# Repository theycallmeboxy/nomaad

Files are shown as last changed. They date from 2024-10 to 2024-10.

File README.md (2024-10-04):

# Nomaad
*A 11 column ortho/alpha gaming keyboard for gamers*

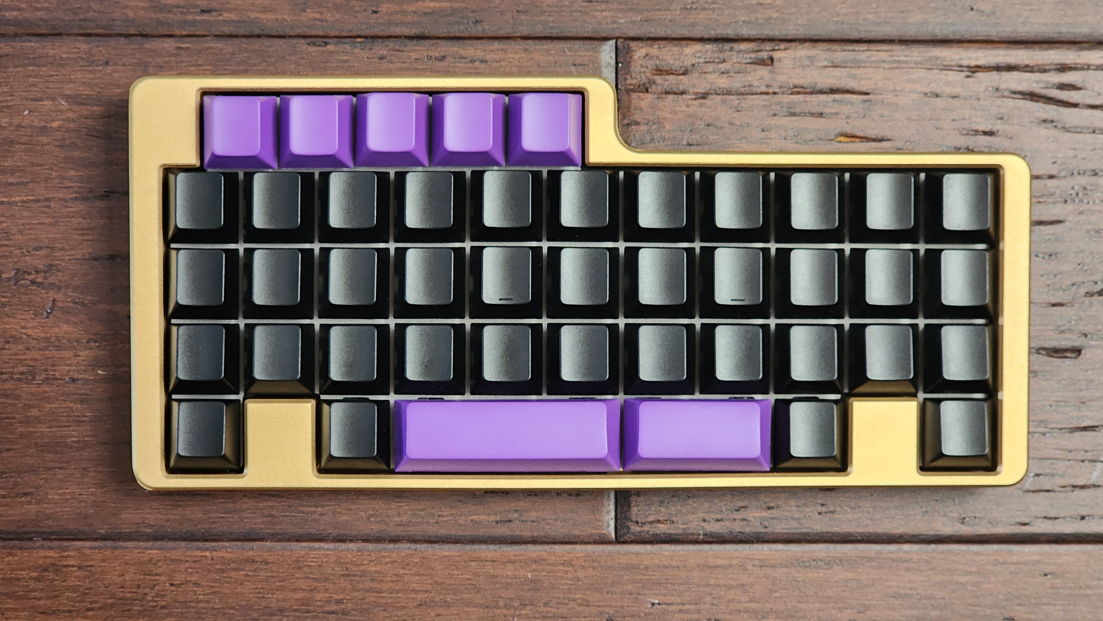
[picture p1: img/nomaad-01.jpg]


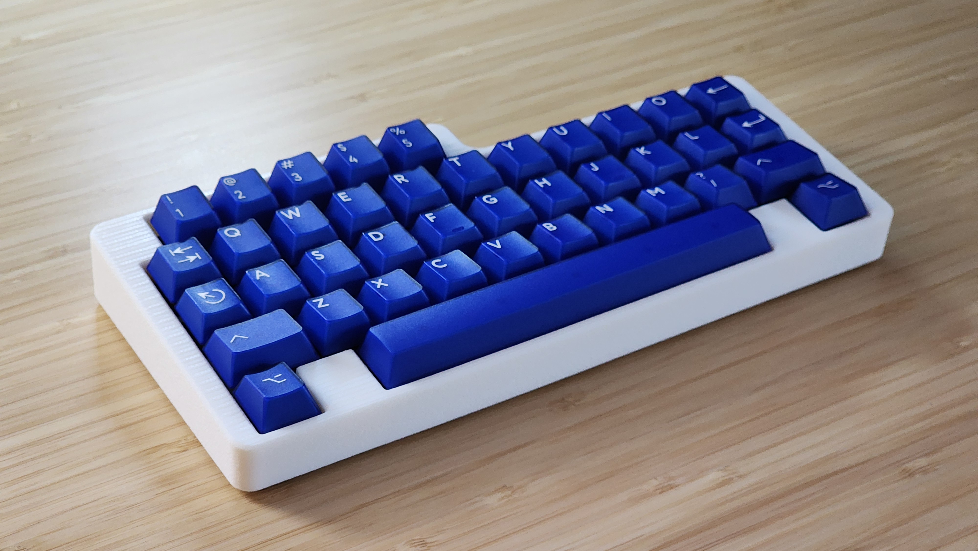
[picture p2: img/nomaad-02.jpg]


**[KLE](https://www.keyboard-layout-editor.com/##@_name=Nomaad%20Vial&author=theycallmeboxy%3B&@_x:0.5%3B&=0,1&=0,2&=0,3&=0,4&=0,5%3B&@=1,0&=1,1&=1,2&=1,3&=1,4&=1,5&=1,6&=1,7&=1,8&=1,9&=1,10%3B&@=2,0&=2,1&=2,2&=2,3&=2,4&=2,5&=2,6&=2,7&=2,8&=2,9&=2,10%3B&@_c=%2300c5ff%3B&=3,0%0A%0A%0A0,0&=3,1%0A%0A%0A0,0&=3,2%0A%0A%0A0,0&=3,3%0A%0A%0A0,0&=3,4%0A%0A%0A0,0&=3,5%0A%0A%0A0,0&=3,6%0A%0A%0A0,0&=3,7%0A%0A%0A0,0&=3,8%0A%0A%0A0,0&=3,9%0A%0A%0A0,0&=3,10%0A%0A%0A0,0%3B&@_c=%23cccccc%3B&=4,0&_x:1&c=%23ffb80c%3B&=4,1%0A%0A%0A1,0&_w:3%3B&=4,3%0A%0A%0A1,0&_w:2%3B&=4,6%0A%0A%0A1,0&=4,7%0A%0A%0A1,0&_x:1&c=%23cccccc%3B&=4,10%3B&@_y:0.5&c=%2300c5ff&w:1.5%3B&=3,0%0A%0A%0A0,1&=3,1%0A%0A%0A0,1&=3,2%0A%0A%0A0,1&=3,3%0A%0A%0A0,1&=3,4%0A%0A%0A0,1&=3,5%0A%0A%0A0,1&=3,6%0A%0A%0A0,1&=3,7%0A%0A%0A0,1&=3,8%0A%0A%0A0,1&_w:1.5%3B&=3,10%0A%0A%0A0,1%3B&@_y:0.25&x:2&c=%23ffb80c&w:7%3B&=4,3%0A%0A%0A1,1)**

## Production Files:

*(Click a link then click download icon in the top right to save a given file to your computer.)*

> [!CAUTION]
> I will assume no responsibility for any cost, damage, or sads resulting from trying to make one of my dumb projects. This project has no implicit support, neither moral nor technical.
> 
> **I'm not a doctor. This is not medical advice. I'm also only a network engineer. You assume all liability in using or reproducing these files.**

Case:
- [Case .stl file](https://github.com/theycallmeboxy/nomaad/blob/main/models/case/nomaad-case.stl)
- [Case .step file](https://github.com/theycallmeboxy/nomaad/blob/main/models/case/nomaad-case.step)

Plate:
- [Ortho stagger plate .dxf file](https://github.com/theycallmeboxy/nomaad/blob/main/models/plate/nomaad-plate_ortho.dxf)
- [Alpha stagger plate .dxf file](https://github.com/theycallmeboxy/nomaad/blob/main/models/plate/nomaad-plate_alpha.dxf)

PCB:
> [!NOTE]
> Version 1 was produced (as prototype 1) without any identified issues.  The gerbers were regenerated to indicate version 1 on the silk and the bom and positions files should be fixed to order as-is.  I have not produced these files yet, but they should be good to go.

- [PCB gerbers .zip file](https://github.com/theycallmeboxy/nomaad/blob/main/pcb/nomaad%20v1/production/nomaad.zip)
- [BOM .csv file](https://github.com/theycallmeboxy/nomaad/blob/main/pcb/nomaad%20v1/production/bom.csv)
- [Positions .csv file](https://github.com/theycallmeboxy/nomaad/blob/main/pcb/nomaad%20v1/production/positions.csv)

Firmware:
- [VIAL Firmware .bin file](https://github.com/theycallmeboxy/nomaad/blob/main/firmware/vial/binary/boxy_nomaad_vial.bin)
  
## Build Notes:

I have made with FDM and CNC aluminum to good effect.  Another 40s member had a resin version manufactured successfully.

**Additional materials:**
 
  - About 18" of .139" (3.53mm) cross section o-ring cord [like this 50A cord](https://www.theoringstore.com/store/index.php?main_page=product_info&cPath=117_527&products_id=18618) or [this 70A cord](https://www.theoringstore.com/store/index.php?main_page=product_info&cPath=117_119&products_id=5058); if you don't want to buy bulk cord, you can cut up an o-ring of like 6" or bigger diameter.
  - 4 SKUF feet like these  [like these](https://keeb.io/products/skuf-silicone-rubber-keyboard-feet).

**Build instructions:**

1. Apply feet to the cutouts.
2. Install stabs if you're into that. 
3. Install switches into the plate and PCB.
4. Solder it up.
5. Friction fit the o-ring cord between the plate and PCB in the positions highlighted in red:

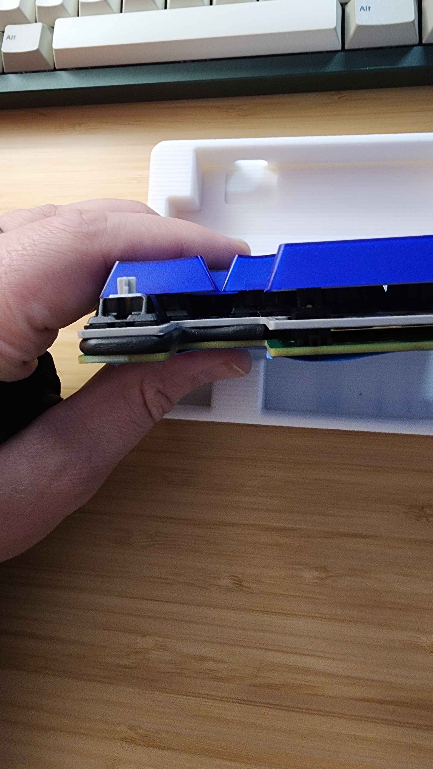
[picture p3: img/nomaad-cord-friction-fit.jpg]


keyborb

6. Insert the assembled PCB number keys first into the case at an angle while aligning the USB port with the cutout.
7. Press the top of the PCB in place, then press in the bottom side (if your cord isn't fully seated, sticks out on the corners, or otherwise catches going in, grab some tweezers and help it stay in between the plate and PCB). 
8. If you need to remove the PCB, pull a few caps off and use a switch puller on the soldered switches.

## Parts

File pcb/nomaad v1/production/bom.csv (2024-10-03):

Designator | Footprint | Quantity | Value | LCSC Part #
BOOT1, RST1 | SW_SPST_TL3342 | 2 | SW_SPST | C318884
C1, C3, C4, C5, C6, C7, C8 | 0402 | 7 | 100nF | C1525
C10, C9 | 0402 | 2 | 1uF | C52923
C2 | 0603 | 1 | 10uF | C19702
D1, D10, D11, D12, D13, D14, D15, D16, D17, D18, D19, D2, D20, D21, D22, D23, D24, D25, D26, D27, D28, D29, D3, D30, D31, D32, D33, D34, D35, D36, D37, D38, D39, D4, D40, D41, D42, D43, D44, D5, D6, D7, D8, D9 | D_SOD-123 | 44 | D | C81598
F1 | 1206 | 1 | 500mA | C369160
J1 | USB_C_Receptacle_HRO_TYPE-C-31-M-12 | 1 | USB_C_Receptacle_USB2.0 | C165948
R1, R2, R3, R4 | 0402 | 4 | 5.1k | C25905
U1 | LQFP-48_7x7mm_P0.5mm | 1 | STM32F072CBT6 | C81720
U2 | SOT-143 | 1 | PRTR5V0U2X | C2827688
U3 | SOT-23 | 1 | XC6206PxxxMR-Regulator_Linear | C5446

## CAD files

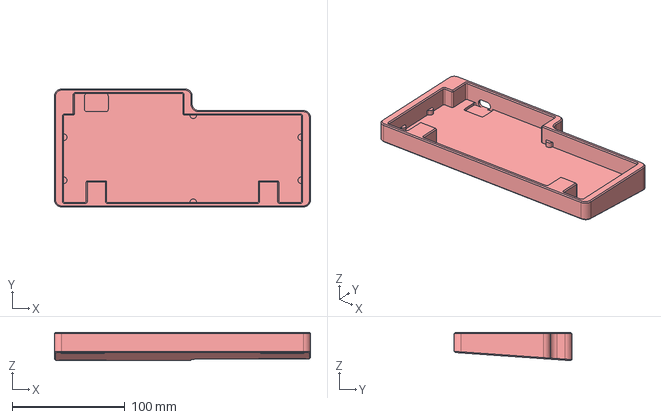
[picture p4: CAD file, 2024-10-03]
models/case/nomaad-case.step
226.6 x 104.3 x 25.0 mm

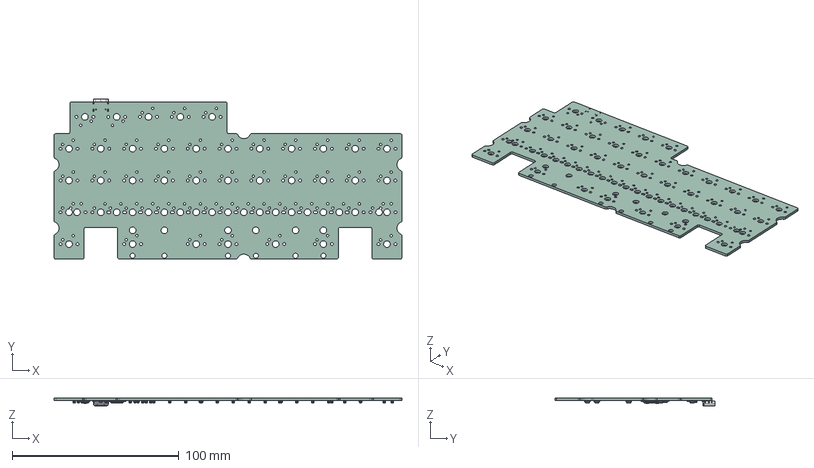
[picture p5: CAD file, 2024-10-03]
models/pcb/nomaad.step
208.5 x 96.0 x 4.85 mm
C_0402_1005Metric x 9
D_SOD_123 x 44
Fuse_1206_3216Metric
SW_SPST_TL3342 x 2
SOT_143
R_0402_1005Metric x 4
LQFP_48_7x7mm_P05mm
CON_TYPE-C-31-M-12 v3
C_0603_1608Metric
SOT_23
nomaad_PCB

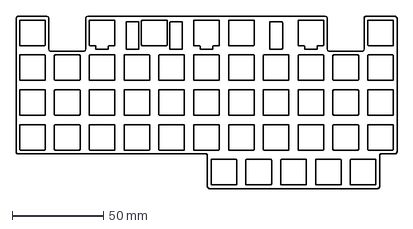
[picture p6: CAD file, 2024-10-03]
models/plate/nomaad-plate_ortho.dxf
208.5 x 94.2 mm

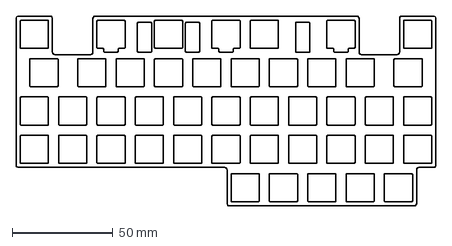
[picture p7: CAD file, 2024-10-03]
models/plate/nomaad-plate_alpha.dxf
208.5 x 94.2 mm

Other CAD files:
models/case/nomaad-case.stl

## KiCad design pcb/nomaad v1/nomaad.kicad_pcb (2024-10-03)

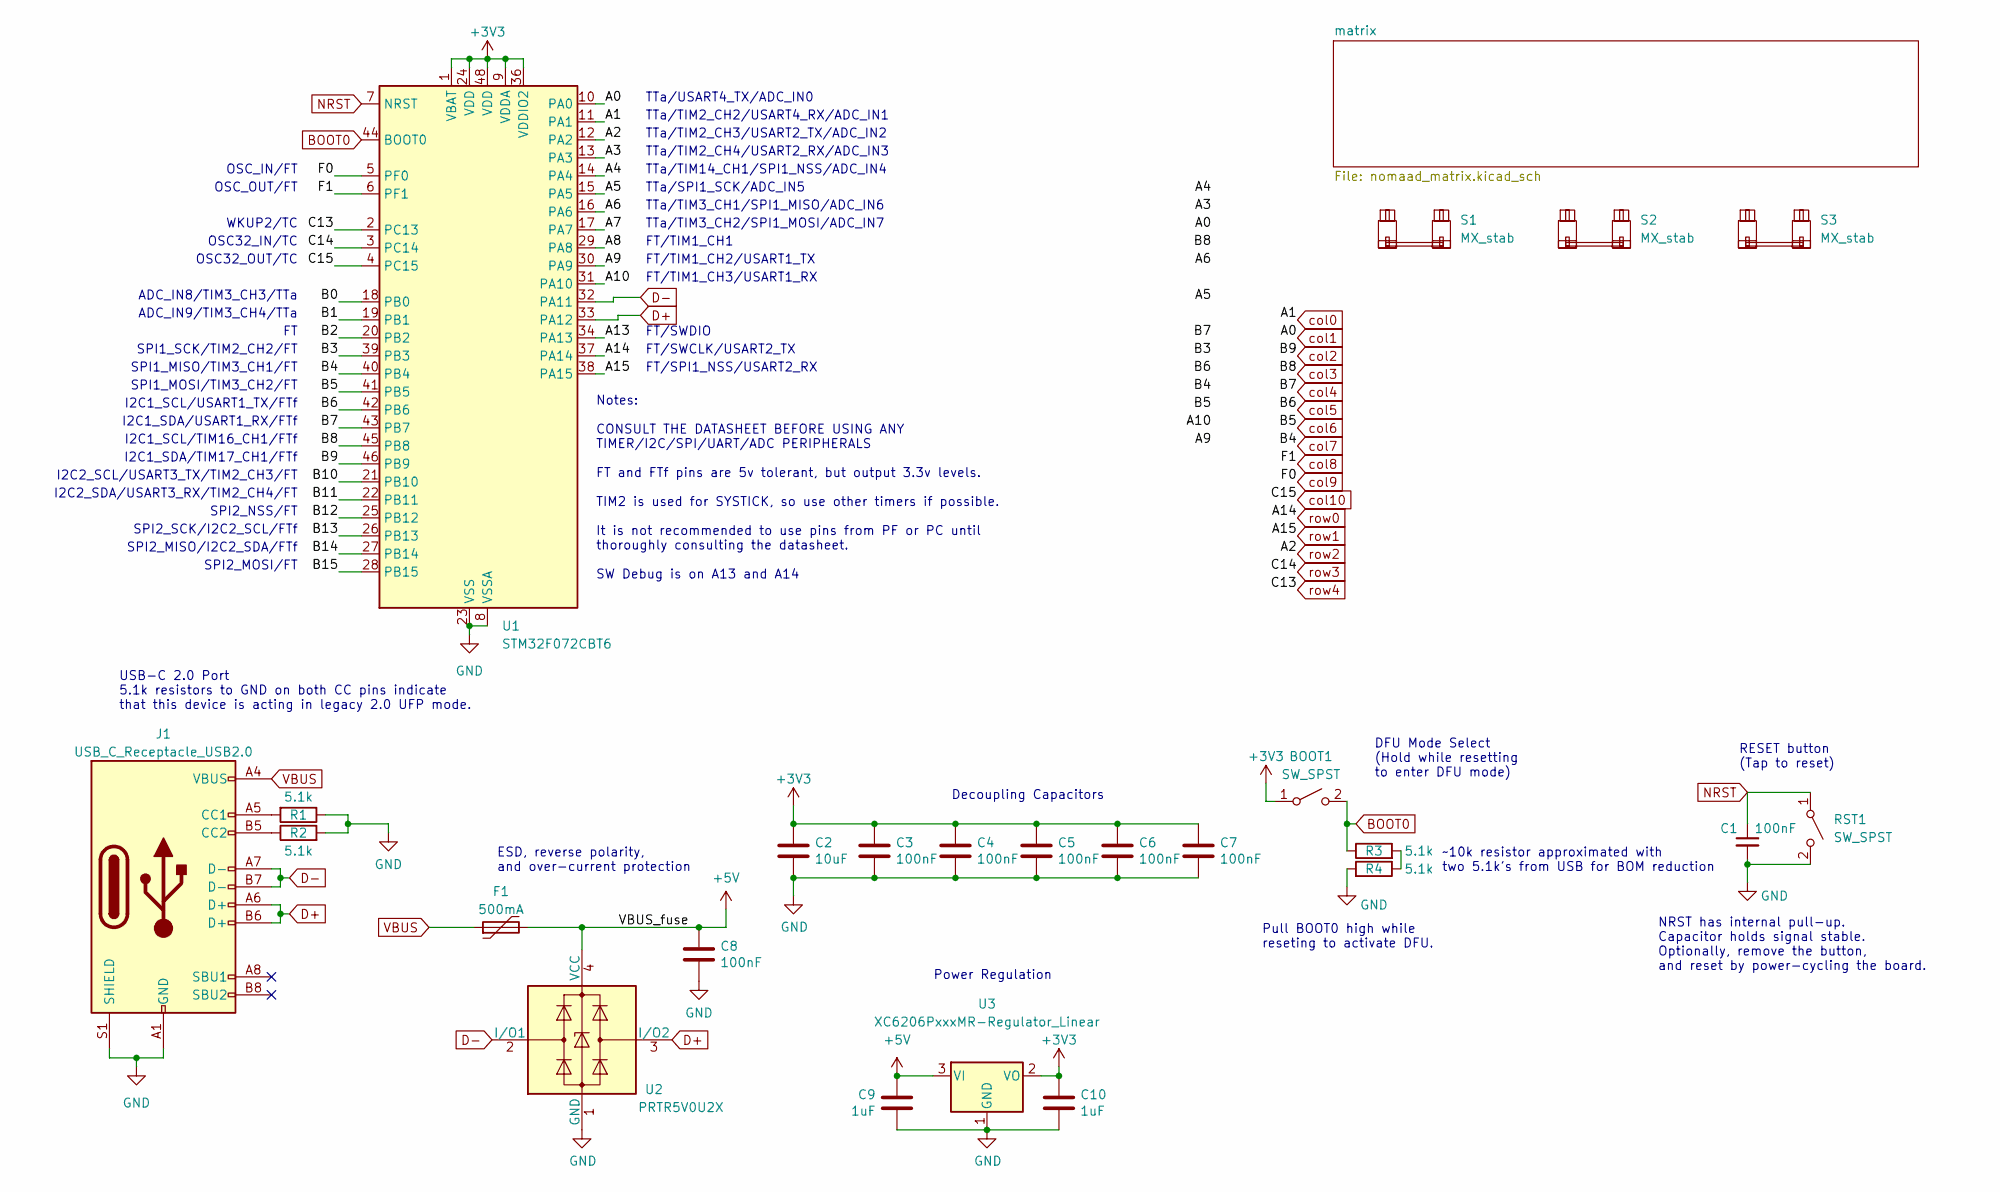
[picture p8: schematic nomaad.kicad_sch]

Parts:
BOOT1: SW_SPST; SW_SPST_TL3342
C1, C3, C4, C5, C6, C7, C8: 100nF; C_0402_1005Metric; LCSC C307331
C2: 10uF; C_0603_1608Metric; LCSC C307331
C9, C10: 1uF; C_0402_1005Metric; LCSC C307331
F1: 500mA; Fuse_1206_3216Metric; LCSC C135341
J1: USB_C_Receptacle_USB2.0; USB_C_Receptacle_HRO_TYPE-C-31-M-12; JlcRotOffset 180
R1, R2, R3, R4: 5.1k; R_0402_1005Metric
RST1: SW_SPST; SW_SPST_TL3342
S1: MX_stab; STAB_MX_7u
S2: MX_stab; STAB_MX_2u
S3: MX_stab; STAB_MX_3u
U1: STM32F072CBT6; LQFP-48_7x7mm_P0.5mm; JlcRotOffset 90
U2: PRTR5V0U2X; SOT-143; LCSC C2827688
U3: XC6206PxxxMR-Regulator_Linear; SOT-23; LCSC C5446

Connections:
+3V3: BOOT1.1 (A), C2.1, C3.1, C4.1, C5.1, C6.1, C7.1, C10.1, U1.1 (VBAT), U1.9 (VDDA), U1.24 (VDD), U1.36 (VDDIO2), U1.48 (VDD), U3.2 (VO)
+5V: C8.1, C9.1, F1.2, U2.4 (VCC), U3.3 (VI)
/A3: U1.13 (PA3)
/A4: U1.14 (PA4)
/A5: U1.15 (PA5)
/A6: U1.16 (PA6)
/A7: U1.17 (PA7)
/A8: U1.29 (PA8)
/A9: U1.30 (PA9)
/A10: U1.31 (PA10)
/A13: U1.34 (PA13)
/B0: U1.18 (PB0)
/B1: U1.19 (PB1)
/B2: U1.20 (PB2)
/B3: U1.39 (PB3)
/B10: U1.21 (PB10)
/B11: U1.22 (PB11)
/B12: U1.25 (PB12)
/B13: U1.26 (PB13)
/B14: U1.27 (PB14)
/B15: U1.28 (PB15)
BOOT0: BOOT1.2 (B), R3.1, U1.44 (BOOT0)
D+: J1.A6 (D+), J1.B6 (D+), U1.33 (PA12), U2.3 (I/O2)
D-: J1.A7 (D-), J1.B7 (D-), U1.32 (PA11), U2.2 (I/O1)
GND: C1.2, C2.2, C3.2, C4.2, C5.2, C6.2, C7.2, C8.2, C9.2, C10.2, J1.A1 (GND), J1.A12 (GND), J1.B1 (GND), J1.B12 (GND), J1.S1 (SHIELD), R1.1, R2.2, R4.2, RST1.2 (B), U1.8 (VSSA), U1.23 (VSS), U1.35 (VSS), U1.47 (VSS), U2.1 (GND), U3.1 (GND)
NRST: C1.1, RST1.1 (A), U1.7 (NRST)
unnamed: J1.A5 (CC1), R1.2
unnamed: J1.B5 (CC2), R2.1
unnamed: R3.2, R4.1
VBUS: F1.1, J1.A4 (VBUS), J1.A9 (VBUS), J1.B4 (VBUS), J1.B9 (VBUS)
col0: U1.11 (PA1); also elsewhere on the board
col1: U1.10 (PA0); also elsewhere on the board
col2: U1.46 (PB9); also elsewhere on the board
col3: U1.45 (PB8); also elsewhere on the board
col4: U1.43 (PB7); also elsewhere on the board
col5: U1.42 (PB6); also elsewhere on the board
col6: U1.41 (PB5); also elsewhere on the board
col7: U1.40 (PB4); also elsewhere on the board
col8: U1.6 (PF1); also elsewhere on the board
col9: U1.5 (PF0); also elsewhere on the board
col10: U1.4 (PC15); also elsewhere on the board
row0: U1.37 (PA14); also elsewhere on the board
row1: U1.38 (PA15); also elsewhere on the board
row2: U1.12 (PA2); also elsewhere on the board
row3: U1.3 (PC14); also elsewhere on the board
row4: U1.2 (PC13); also elsewhere on the board

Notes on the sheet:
I2C2_SCL/USART3_TX/TIM2_CH3/FT
TTa/TIM2_CH2/USART4_RX/ADC_IN1
OSC_IN/FT
Decoupling Capacitors
DFU Mode Select (Hold while resetting to enter DFU mode)
OSC32_IN/TC
SPI2_MISO/I2C2_SDA/FTf
SPI2_MOSI/FT
SPI1_SCK/TIM2_CH2/FT
I2C2_SDA/USART3_RX/TIM2_CH4/FT
OSC_OUT/FT
Power Regulation
TTa/TIM14_CH1/SPI1_NSS/ADC_IN4
Pull BOOT0 high while reseting to activate DFU.
FT/TIM1_CH2/USART1_TX
SPI2_SCK/I2C2_SCL/FTf
ADC_IN8/TIM3_CH3/TTa
TTa/SPI1_SCK/ADC_IN5
I2C1_SDA/TIM17_CH1/FTf
I2C1_SCL/USART1_TX/FTf
WKUP2/TC
FT/TIM1_CH1
TTa/USART4_TX/ADC_IN0
USB-C 2.0 Port 5.1k resistors to GND on both CC pins indicate that this device is acting in legacy 2.0 UFP mode.
ESD, reverse polarity, and over-current protection
NRST has internal pull-up. Capacitor holds signal stable. Optionally, remove the button, and reset by power-cycling the board.
OSC32_OUT/TC
~10k resistor approximated with two 5.1k's from USB for BOM reduction
I2C1_SDA/USART1_RX/FTf
TTa/TIM3_CH2/SPI1_MOSI/ADC_IN7
TTa/TIM2_CH4/USART2_RX/ADC_IN3
ADC_IN9/TIM3_CH4/TTa
SPI1_MOSI/TIM3_CH2/FT
FT/SPI1_NSS/USART2_RX
FT/SWCLK/USART2_TX
SPI2_NSS/FT
FT/SWDIO
I2C1_SCL/TIM16_CH1/FTf
FT/TIM1_CH3/USART1_RX
TTa/TIM3_CH1/SPI1_MISO/ADC_IN6

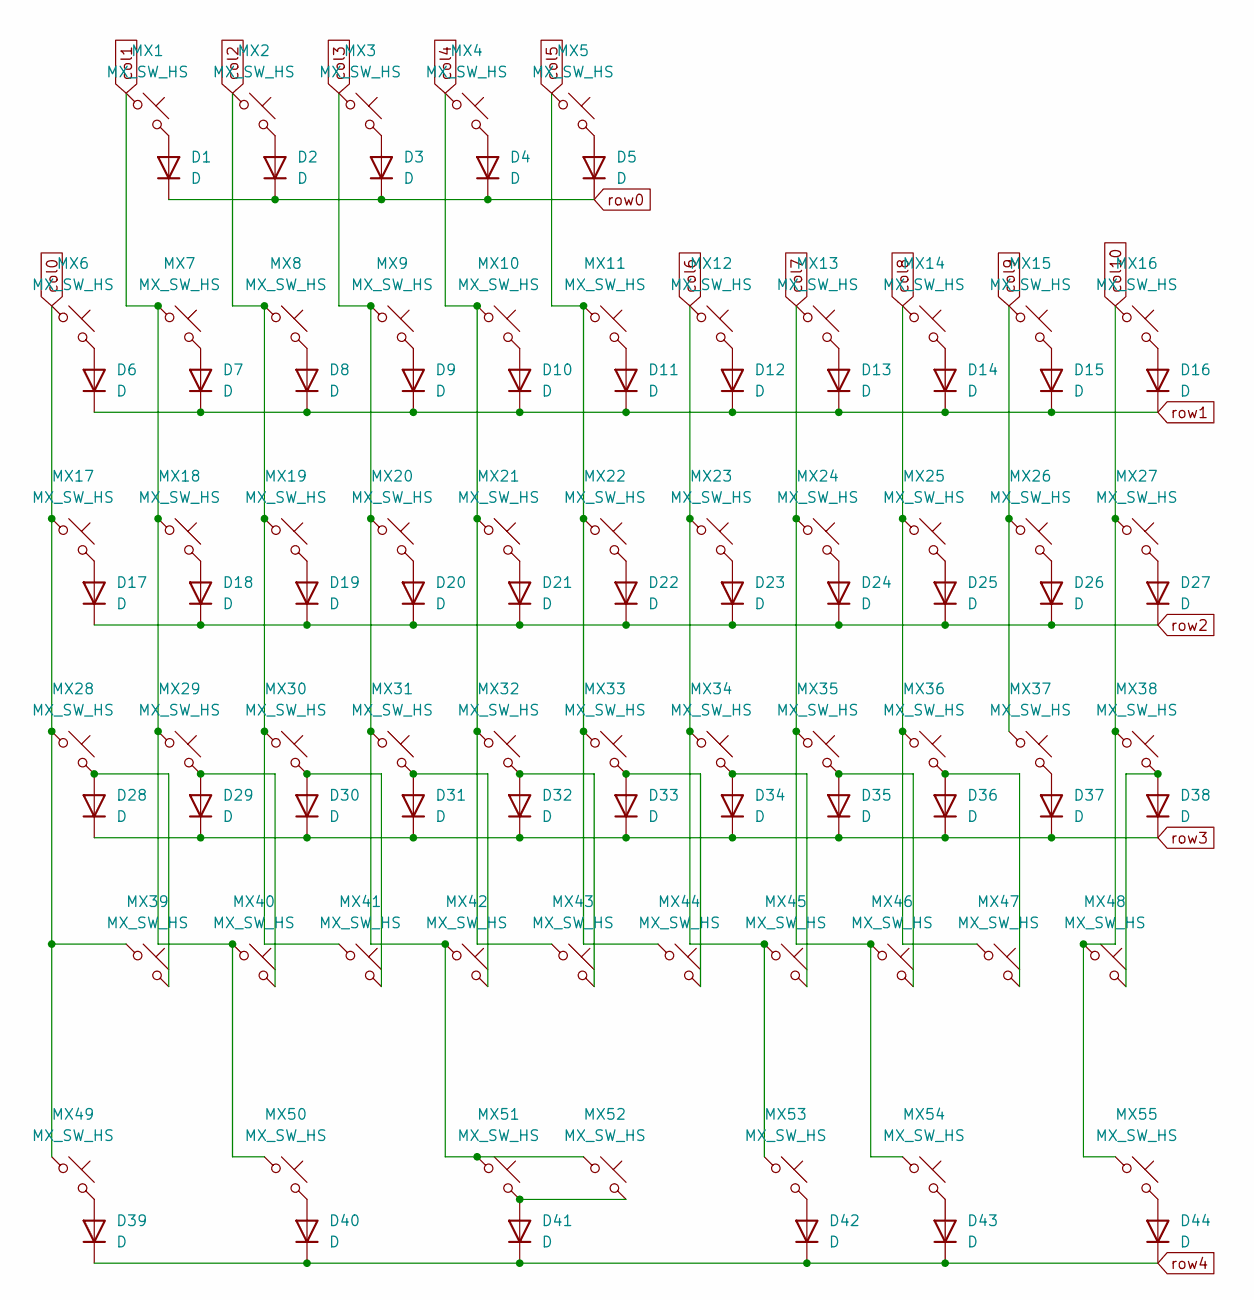
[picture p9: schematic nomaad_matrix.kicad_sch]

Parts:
D1, D2, D3, D4, D5, D6, D7, D8, D9, D10, D11, D12, D13, D14, D15, D16, D17, D18, D19, D20, D21, D22, D23, D24, D25, D26, D27, D28, D29, D30, D31, D32, D33, D34, D35, D36, D37, D38, D39, D40, D41, D42, D43, D44: D; D_SOD-123
MX1, MX2, MX3, MX4, MX5, MX6, MX7, MX8, MX9, MX10, MX11, MX12, MX13, MX14, MX15, MX16, MX17, MX18, MX19, MX20, MX21, MX22, MX23, MX24, MX25, MX26, MX27, MX28, MX29, MX30, MX31, MX32, MX33, MX34, MX35, MX36, MX37, MX38, MX39, MX40, MX41, MX42, MX43, MX44, MX45, MX46, MX47, MX48, MX49, MX50, MX51, MX52, MX53, MX54, MX55: MX_SW_HS; SW_MX_1u

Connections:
unnamed: D1.2 (A), MX1.2
unnamed: D2.2 (A), MX2.2
unnamed: D3.2 (A), MX3.2
unnamed: D4.2 (A), MX4.2
unnamed: D5.2 (A), MX5.2
unnamed: D6.2 (A), MX6.2
unnamed: D7.2 (A), MX7.2
unnamed: D8.2 (A), MX8.2
unnamed: D9.2 (A), MX9.2
unnamed: D10.2 (A), MX10.2
unnamed: D11.2 (A), MX11.2
unnamed: D12.2 (A), MX12.2
unnamed: D13.2 (A), MX13.2
unnamed: D14.2 (A), MX14.2
unnamed: D15.2 (A), MX15.2
unnamed: D16.2 (A), MX16.2
unnamed: D17.2 (A), MX17.2
unnamed: D18.2 (A), MX18.2
unnamed: D19.2 (A), MX19.2
unnamed: D20.2 (A), MX20.2
unnamed: D21.2 (A), MX21.2
unnamed: D22.2 (A), MX22.2
unnamed: D23.2 (A), MX23.2
unnamed: D24.2 (A), MX24.2
unnamed: D25.2 (A), MX25.2
unnamed: D26.2 (A), MX26.2
unnamed: D27.2 (A), MX27.2
unnamed: D28.2 (A), MX28.2, MX39.2
unnamed: D29.2 (A), MX29.2, MX40.2
unnamed: D30.2 (A), MX30.2, MX41.2
unnamed: D31.2 (A), MX31.2, MX42.2
unnamed: D32.2 (A), MX32.2, MX43.2
unnamed: D33.2 (A), MX33.2, MX44.2
unnamed: D34.2 (A), MX34.2, MX45.2
unnamed: D35.2 (A), MX35.2, MX46.2
unnamed: D36.2 (A), MX36.2, MX47.2
unnamed: D37.2 (A), MX37.2
unnamed: D38.2 (A), MX38.2, MX48.2
unnamed: D39.2 (A), MX49.2
unnamed: D40.2 (A), MX50.2
unnamed: D41.2 (A), MX51.2, MX52.2
unnamed: D42.2 (A), MX53.2
unnamed: D43.2 (A), MX54.2
unnamed: D44.2 (A), MX55.2
col0: MX6.1, MX17.1, MX28.1, MX39.1, MX49.1; also elsewhere on the board
col1: MX1.1, MX7.1, MX18.1, MX29.1, MX40.1, MX50.1; also elsewhere on the board
col2: MX2.1, MX8.1, MX19.1, MX30.1, MX41.1; also elsewhere on the board
col3: MX3.1, MX9.1, MX20.1, MX31.1, MX42.1, MX51.1, MX52.1; also elsewhere on the board
col4: MX4.1, MX10.1, MX21.1, MX32.1, MX43.1; also elsewhere on the board
col5: MX5.1, MX11.1, MX22.1, MX33.1, MX44.1; also elsewhere on the board
col6: MX12.1, MX23.1, MX34.1, MX45.1, MX53.1; also elsewhere on the board
col7: MX13.1, MX24.1, MX35.1, MX46.1, MX54.1; also elsewhere on the board
col8: MX14.1, MX25.1, MX36.1, MX47.1; also elsewhere on the board
col9: MX15.1, MX26.1, MX37.1; also elsewhere on the board
col10: MX16.1, MX27.1, MX38.1, MX48.1, MX55.1; also elsewhere on the board
row0: D1.1 (K), D2.1 (K), D3.1 (K), D4.1 (K), D5.1 (K); also elsewhere on the board
row1: D6.1 (K), D7.1 (K), D8.1 (K), D9.1 (K), D10.1 (K), D11.1 (K), D12.1 (K), D13.1 (K), D14.1 (K), D15.1 (K), D16.1 (K); also elsewhere on the board
row2: D17.1 (K), D18.1 (K), D19.1 (K), D20.1 (K), D21.1 (K), D22.1 (K), D23.1 (K), D24.1 (K), D25.1 (K), D26.1 (K), D27.1 (K); also elsewhere on the board
row3: D28.1 (K), D29.1 (K), D30.1 (K), D31.1 (K), D32.1 (K), D33.1 (K), D34.1 (K), D35.1 (K), D36.1 (K), D37.1 (K), D38.1 (K); also elsewhere on the board
row4: D39.1 (K), D40.1 (K), D41.1 (K), D42.1 (K), D43.1 (K), D44.1 (K); also elsewhere on the board

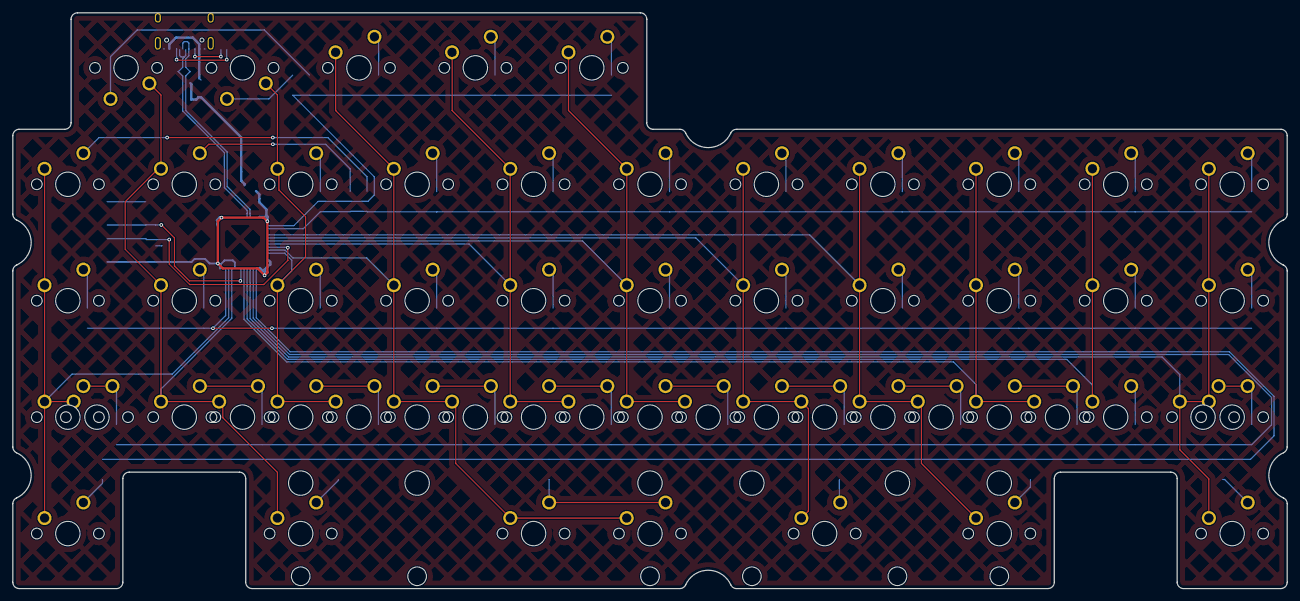
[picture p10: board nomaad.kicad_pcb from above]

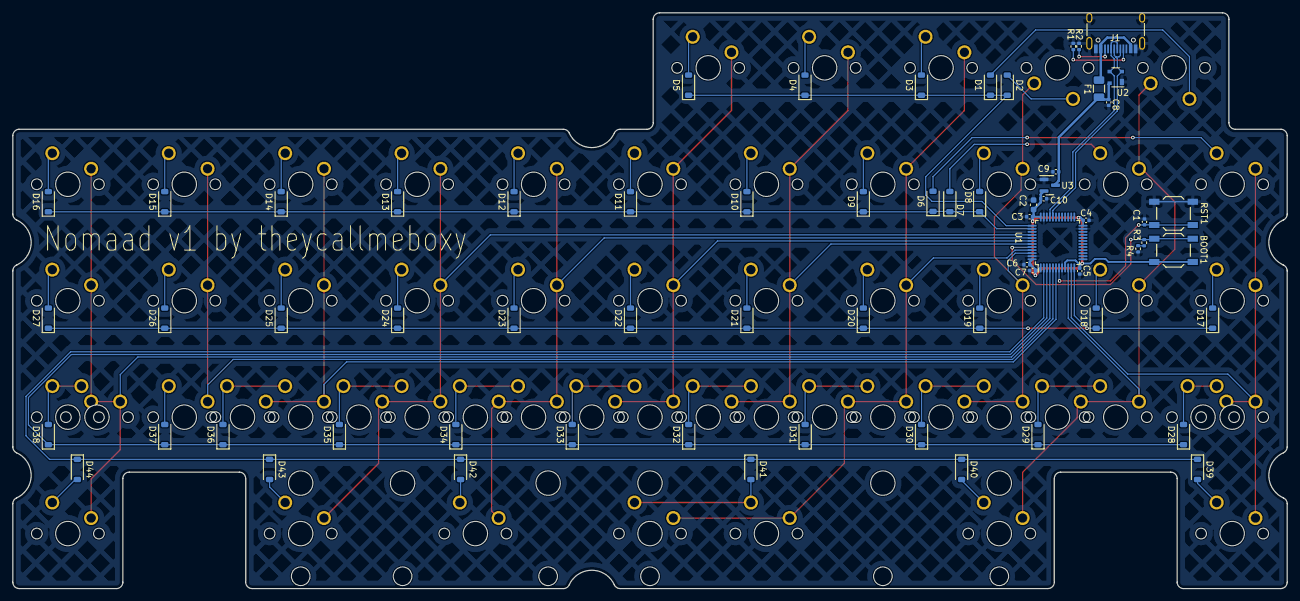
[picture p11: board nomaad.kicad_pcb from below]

Board: 2 copper layers, 208.5 x 94.2 mm, 123 parts (65 on the bottom side), 71 nets.
